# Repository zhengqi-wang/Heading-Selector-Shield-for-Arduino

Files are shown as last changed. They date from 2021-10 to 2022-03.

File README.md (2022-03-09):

# Heading-Selector-Shield-for-Arduino
Arduino shield as a heading selector for flight simulator games. Can be also used as course selector or other applications.

Not for aviation training purpose! Use at your own risk.

Full HDG selecter functionality can be achieved in FS2020.

SimHDG.ino is the main source file. It is used with FS2020 to Arduino. https://github.com/Seahawk240/Microsoft-FS2020-To-Arduino 

SimInterfaceHDGv2.ino is a test file. The encoder controls the display value from 000 to 999.

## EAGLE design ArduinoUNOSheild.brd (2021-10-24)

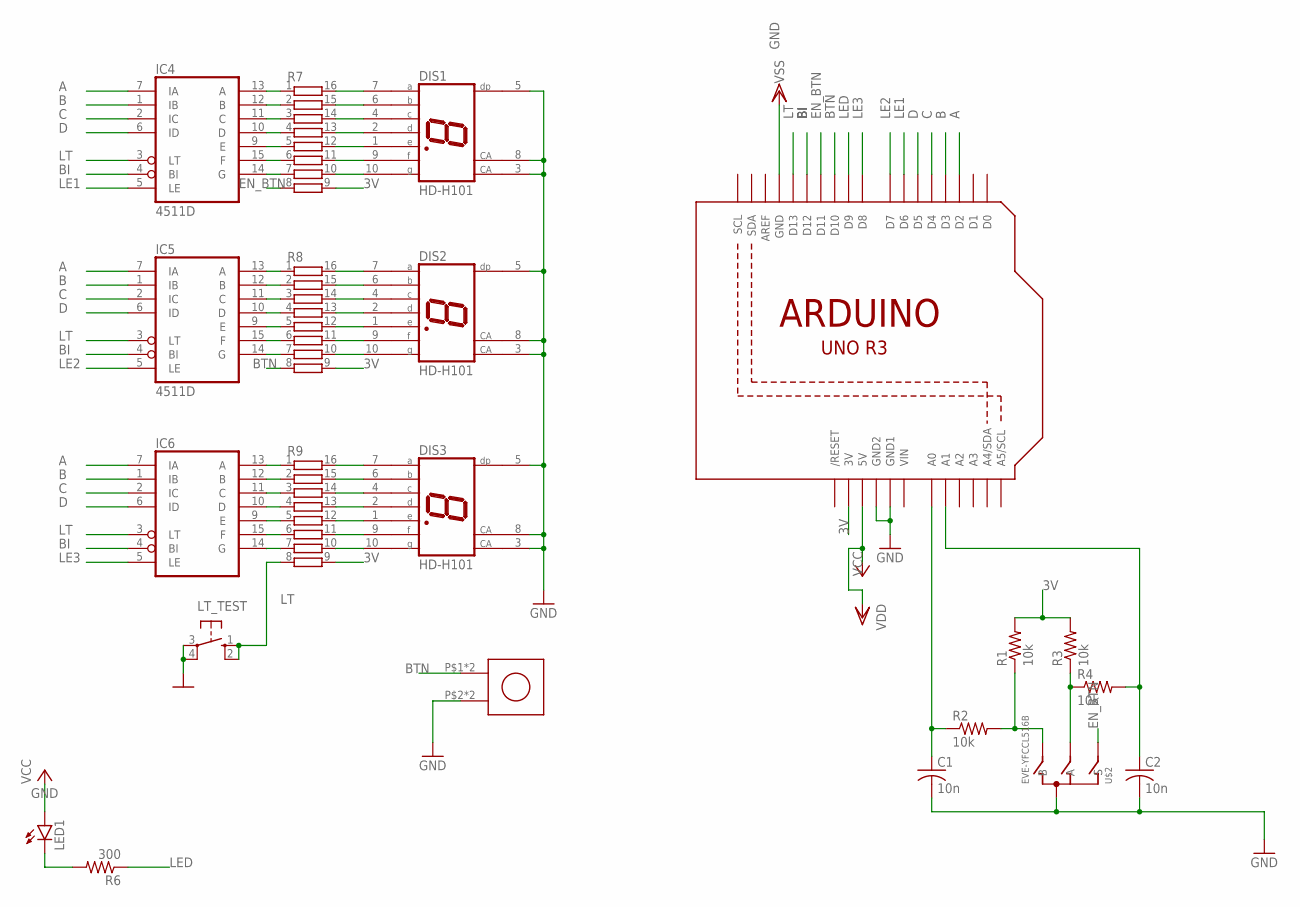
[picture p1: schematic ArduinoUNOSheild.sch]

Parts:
C1, C2: 10n; C0603
DIS1, DIS2, DIS3: HD-H101; HDSP-M
IC4, IC5, IC6: 4511D; SO16
LED1: LEDCHIP-LED0805; CHIP-LED0805
LT_TEST: 10-XX; B3F-10XX
R1, R2, R3, R4: 10k; R0603
R6: 300; R0603
R7, R8, R9: 4816P-T01; 4816P
U1: ARDUINOR3-NOIOREF-NOTEXT; ARDUINOR3-NOTEXT-NOIOREF
U$1: AE1027; BUTTON5X13MM
U$2: EVE-YFCCL516B; PANASONIC_EVE_Y

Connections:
3V: R1.2, R3.2, R7.9, R8.9, R9.9, U1.3V
A: IC4.7 (IA), IC5.7 (IA), IC6.7 (IA), U1.D2
A1: C2.1, R4.2, U1.A1
B: IC4.1 (IB), IC5.1 (IB), IC6.1 (IB), U1.D3
BI: IC4.4 (BI), IC5.4 (BI), IC6.4 (BI), U1.D12
BTN: R8.8, U1.D10, U$1.P$1, U$1.P$11
C: IC4.2 (IC), IC5.2 (IC), IC6.2 (IC), U1.D4
D: IC4.6 (ID), IC5.6 (ID), IC6.6 (ID), U1.D5
EN_BTN: R7.8, U1.D11, U$2.S
GND: C1.2, C2.2, DIS1.3 (CA), DIS1.5 (DP), DIS1.8 (CA), DIS2.3 (CA), DIS2.5 (DP), DIS2.8 (CA), DIS3.3 (CA), DIS3.5 (DP), DIS3.8 (CA), IC4.8 (VSS), IC5.8 (VSS), IC6.8 (VSS), LT_TEST.3, LT_TEST.4 (P1), U1.GND, U1.GND1, U1.GND2, U$1.P$2, U$1.P$12, U$2.COM (C), U$2.GND (C), U$2.GND1 (C)
LE1: IC4.5 (LE), U1.D6
LE2: IC5.5 (LE), U1.D7
LE3: IC6.5 (LE), U1.D8
LED: R6.1, U1.D9
LED_N: LED1.C, R6.2
LT: IC4.3 (LT), IC5.3 (LT), IC6.3 (LT), LT_TEST.1 (S), LT_TEST.2 (S1), R9.8, U1.D13
unnamed: DIS1.7 (A), R7.16
unnamed: DIS1.6 (B), R7.15
unnamed: DIS1.4 (C), R7.14
unnamed: DIS1.2 (D), R7.13
unnamed: DIS1.1 (E), R7.12
unnamed: DIS1.9 (F), R7.11
unnamed: DIS1.10 (G), R7.10
unnamed: DIS2.7 (A), R8.16
unnamed: DIS2.6 (B), R8.15
unnamed: DIS2.4 (C), R8.14
unnamed: DIS2.2 (D), R8.13
unnamed: DIS2.1 (E), R8.12
unnamed: DIS2.9 (F), R8.11
unnamed: DIS2.10 (G), R8.10
unnamed: DIS3.7 (A), R9.16
unnamed: DIS3.6 (B), R9.15
unnamed: DIS3.4 (C), R9.14
unnamed: DIS3.2 (D), R9.13
unnamed: DIS3.1 (E), R9.12
unnamed: DIS3.9 (F), R9.11
unnamed: DIS3.10 (G), R9.10
unnamed: R1.1, R2.2, U$2.B, U$2.B1 (B)
unnamed: C1.1, R2.1, U1.A0
unnamed: R3.1, R4.1, U$2.A
unnamed: IC4.13 (A), R7.1
unnamed: IC4.12 (B), R7.2
unnamed: IC4.11 (C), R7.3
unnamed: IC4.10 (D), R7.4
unnamed: IC4.9 (E), R7.5
unnamed: IC4.15 (F), R7.6
unnamed: IC4.14 (G), R7.7
unnamed: IC5.13 (A), R8.1
unnamed: IC5.12 (B), R8.2
unnamed: IC5.11 (C), R8.3
unnamed: IC5.10 (D), R8.4
unnamed: IC5.9 (E), R8.5
unnamed: IC5.15 (F), R8.6
unnamed: IC5.14 (G), R8.7
unnamed: IC6.13 (A), R9.1
unnamed: IC6.12 (B), R9.2
unnamed: IC6.11 (C), R9.3
unnamed: IC6.10 (D), R9.4
unnamed: IC6.9 (E), R9.5
unnamed: IC6.15 (F), R9.6
unnamed: IC6.14 (G), R9.7
VCC: IC4.16 (VDD), IC5.16 (VDD), IC6.16 (VDD), LED1.A, U1.5V
VIN: U1.VIN

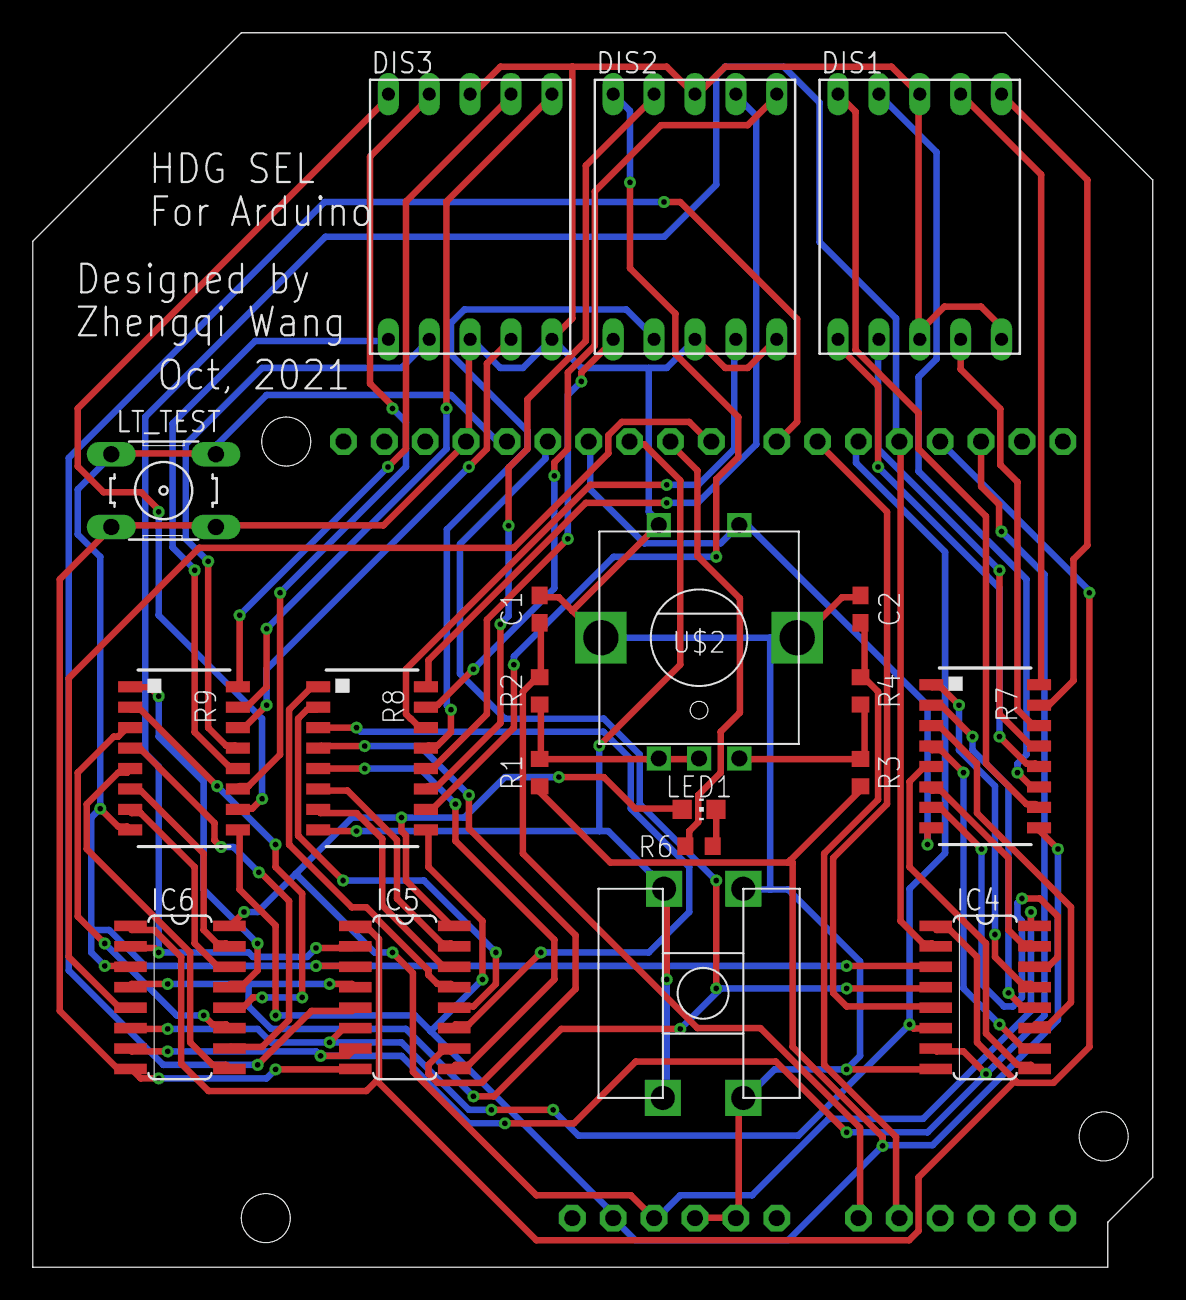
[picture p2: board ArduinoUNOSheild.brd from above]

Board: 2 copper layers, 69.6 x 76.7 mm, 21 parts (0 on the bottom side), 62 nets.

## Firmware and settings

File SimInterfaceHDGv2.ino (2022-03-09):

//Sample using LiquidCrystal library
//#include <LiquidCrystal.h>
#include <TimerOne.h>
#include <ClickEncoder.h>
//#include <Encoder.h>
/*******************************************************

This program will test the LCD panel and the buttons
Mark Bramwell, July 2010

********************************************************/
// select the pins used on the LCD panel
//LiquidCrystal lcd(8, 9, 4, 5, 6, 7);
//Encoder enc(A0,A1);
ClickEncoder *encoder;

bool led_state=HIGH;

//int pins[3][4]={{0,1,2,3},{4,5,6,7},{8,9,10,11}};
int pins[4]={2,3,4,5};
int bit_id[3]={6,7,8};
float dis_value=888;
const int led_pin=9;
const int btn=10;
const int en_btn=11;
const int bi=12;
const int lt=13;
float vs=0;
int hdg_sel=0;
int alt_sel=0;
int spd_sel=0;
 int counter = 0; 
 int currentStateCLK;
 int previousStateCLK; 

int16_t last, value;

void timerIsr() {
  encoder->service();
}

void getDataFromFS2020(void);

void toggle_led(void)
{
  if(led_state==LOW)
  {
    led_state=HIGH;
    digitalWrite(led_pin, led_state);
  }
  else
  {
    led_state=LOW;
    analogWrite(led_pin, 100);
  }
  
}
void set_led(void)
{
  analogWrite(led_pin, 100);
}
void set_led_state(void)
{
  digitalWrite(led_pin, led_state);
}
void set_dis_single(int _id, int _value)
{
  digitalWrite(bit_id[_id], LOW);
  for(int i=0;i<4;i++)
  {
    bool state=bitRead(_value, i);  
    digitalWrite(pins[i],state);
  }
  delay(20);
  digitalWrite(bit_id[_id], HIGH);
}
void set_dis(int _value)
{
  int value1[3]={0,0,0};
   value1[2]=_value/100;
   value1[1]=(_value-value1[2]*100)/10;
   value1[0]=_value-value1[2]*100-value1[1]*10;
  for(int i=0;i<3;i++)
  {
    set_dis_single(i,value1[i]);
  }
}

void setup()
{
  Serial.begin(9600);
  encoder = new ClickEncoder(A0, A1, 11);
  Timer1.initialize(1000);
  Timer1.attachInterrupt(timerIsr); 
  
  last = -1;
  
  pinMode(led_pin, OUTPUT);
  pinMode(bi, OUTPUT);
  for(int i=2;i<10;i++)
  {
    pinMode(i, OUTPUT);
  }
  pinMode(btn, INPUT_PULLUP);
  pinMode(en_btn, INPUT_PULLUP);
 pinMode(lt, INPUT);
//  set_dis(dis_value);
  digitalWrite(led_pin, led_state);
  digitalWrite(bi, HIGH);
}

long oldPosition  = -999;
int dis_value_old=0;
void loop()
{   
  value = encoder->getValue();
//  long newPosition = enc.read();
//  if (newPosition != oldPosition) {
//    long poserr=newPosition-oldPosition;
//    oldPosition = newPosition;
    dis_value+=float(value)/2;
//    Serial.println(dis_value);
//    Serial.println(newPosition);
//  }
   
//  getDataFromFS2020();

  if(digitalRead(lt)==LOW)
  {
    set_led();
  }
  else
  {
    set_led_state();
  }

  if(digitalRead(en_btn)==LOW)
  {
    dis_value=0;
  }
  if(digitalRead(btn)==LOW)
  {
    toggle_led();
    delay(200);
  }  
  dis_value=max(min(dis_value,999),0);
  if(dis_value != dis_value_old)
  {
    set_dis(int(dis_value));
  }
  dis_value_old=dis_value;
}

void getDataFromFS2020() {
  //Declaration of variables to store the incoming data
  String input = "@"; //General input buffer
  int value;  //Value memory
  int index;  //Index memory
 if (Serial.available() > 0) {
    Serial.readStringUntil('@'); //Look out for first Indicator
    input += Serial.readStringUntil('/') + "/"; //read the ID
    index = Serial.readStringUntil('=').toInt();    
    
    if (input.indexOf("@763/") != -1) { //Check for Vertical Speed ID
      vs = Serial.readStringUntil('$').toInt();  //Saves the value as int to "value" Variable for later use
        
      //Do something with the values...
      //like displaying or sending something
      //Or include a function like:
      //void refreshStepperMotorPosition(int value)

    } 

        if (input.indexOf("@86/") != -1) { //Check for Vertical Speed ID
      hdg_sel = Serial.readStringUntil('$').toInt();  //Saves the value as int to "value" Variable for later use
        
      //Do something with the values...
      //like displaying or sending something
      //Or include a function like:
      //void refreshStepperMotorPosition(int value)

    } 
//    if (input.indexOf("@90/") != -1) { //Check for AP Master ID -> Gives Bool Value
//      value = Serial.readStringUntil('$').toInt();  //Saves the value as int to "value" Variable for later use
//
//      if (value == 1) {
//        //do something
//        Serial.print("@465/1$"); //Turns landing lights on when AP is on        
//      } else {
//        //do something else
//        Serial.print("@465/0$"); //Turns landing lights on when AP is off        
//      }
//    }
  }
}
